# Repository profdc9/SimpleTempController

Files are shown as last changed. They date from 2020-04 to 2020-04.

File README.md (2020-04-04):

This is a simple temperature controller based on an Arduino that is intended to be used with an improvised dry heat disinfection unit that operates at 60 to 100 C.  The disinfection unit uses a small metal bucket and lid as the disinfection chamber and incandescent light bulbs as the heating elements which should be available at hardware stores.  The unit is designed to be readily constructible for use in a crisis or pandemic situation where dry heat disinfection is applied to personal protective equipment (PPE).

It is intentionally simple, requiring the minimum specialized parts, so it can be built with parts that are on-hand or readily available.  The main specialized parts are an Arduino Nano or Arduino Uno and a LM35 temperature sensing IC.  The user interface is four LEDs and three push buttons.  A PCB layout is available for a version that uses the Arduino Nano V3.  The PCB is one-sided an a stencil is provided for etching a circuit board.  Because the disinfection unit uses mains power, precautions should be taken to prevent electric shock.

Directories:

-	code: Arduino project
-	doc: Documents describing how to construct and use the improvised dry heat disinfection unit.
- 	SimpleTempController: KiCad PCB layout.  

The PCB was created by Daniel Marks and is available under the Creative Commons CC-BY-SA 4.0 licenses, and the software was also created by Daniel Marks and is available under the zlib license.  THE HARDWARE AND SOFTWARE IS PROVIDED "AS IS", WITHOUT WARRANTY OF ANY KIND, EXPRESS OR IMPLIED, INCLUDING BUT NOT LIMITED TO THE WARRANTIES OF MERCHANTABILITY, FITNESS FOR A PARTICULAR PURPOSE AND NONINFRINGEMENT. IN NO EVENT SHALL THE AUTHORS OR COPYRIGHT HOLDERS BE LIABLE FOR ANY CLAIM, DAMAGES OR OTHER LIABILITY, WHETHER IN AN ACTION OF CONTRACT, TORT OR OTHERWISE, ARISING FROM, OUT OF OR IN CONNECTION WITH THE HARDWARE AND SOFTWARE OR THE USE OR OTHER DEALINGS IN THE HARDWARE AND SOFTWARE.

For any questions, please contact Daniel Marks, profdc9@gmail.com

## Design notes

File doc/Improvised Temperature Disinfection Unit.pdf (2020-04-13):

An improvised temperature controller for a heat disinfection cabinet by Daniel L. Marks

Rev1: March 29, 2020
Rev2: April 3, 2020
Rev3: April 13, 2020

WARNING:
These instructions are followed at your own risk.
By proceeding further, you agree to take all necessary safety precautions. In no event, should the author of this document be liable for any damages whatsoever. If you live in a jurisdiction that does not allow the exclusion of liabilities, then you should not proceed further. Because this project involves disinfection of deadly pathogens, possible electrocution from mains voltages, possible fire hazards from heating elements, and a variety of other potentially harmful and deadly risks, the author disclaims responsibility for the use of this document. This work is intended as an improvised device to disinfect PPE with dry heating in a pandemic crisis situation. Please take proper precautions around mains power and ensure that overheating does not occur. It is recommended that one read over these directions before starting the project.

Abstract: Studies have shown that the viruses on personal protective equipment (PPE), such as N95 masks, may be deactivated by the application of sufficient heat for a sufficient duration of time while preserving the function of the PPE. Successful treatment requires control of both the temperature and duration of the applied heat. This document describes an improvised heat disinfection cabinet which includes a temperature controller. The heating element is a common non-halogen incandescent light bulb, while the temperature control is construct from commonly available electrical components such as an Arduino Nano, relays, LEDs, and buttons. To construct the incandescent light heater, the constructor should be familiar with precautions taken when working with mains voltages, especially if an existing lamp is modified for this purpose.

It is recommended that one read over these directions before starting the project.

The project github which includes source code, schematics, and a PCB board layout, is located at

http://www.github.com/profdc9/SimpleTempController

Parts necessary for the temperature controller

- Arduino Nano V3, Arduino Nano, or Arduino Uno
- Pin socket headers for the Arduino Nano if it is not to be soldered directly into the PCB.
- LM35 temperature sensing IC in TO-92 package
- 7 1 kW 1/4 watt resistor
- 1 10 kW 1/4 watt resistor
- 1 100 W 1/4 watt resistor

“An improvised temperature controller for a heat disinfection cabinet,” by Daniel L. Marks. Please
refer to the warnings on page one. | 1

- 2 Small single NPN BJTs, examples: 2N2222A, 2N3904, BC548. As seen from the flat side, 2N2222A and 2N3904 have emitter, base, collector left-to-right as viewed from the flat side, while BC548 is the opposite: collector, base, emitter left-to-right as viewed from the flat side.
- 2 Small silicon diodes, examples: 1N4148, 1N4001, 1N4007, etc. The black band corresponds to the cathode, or the terminal of the diode on the schematic with the thin line (not the arrow).
- 1 100 nF ceramic disc capacitor, 25 volts
- 4 LEDs (any color)
- 3 Single pole-single throw (SPST) momentary contact (push button) normally open switch. If possible, make button #3 a different color (by selection or marking) than buttons #1 and #2. For example, make button #3 red and buttons #1 and #2 black. This is because one can simply instruct a user to turn on the device and press the red button to start the heating cycle.
- 1 Single-pole single-throw (SPST) or single-pole double throw (SPDT) 5 volt coil relay, 250 VAC voltage rated relay. Example: SONGLE SRD-05VDC-SL-C relay. A module such as shown below is better for connection because it has screw terminals but may not be available.

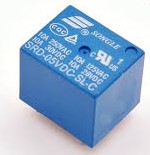
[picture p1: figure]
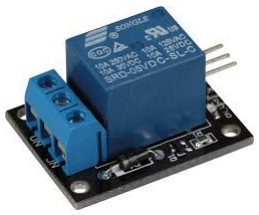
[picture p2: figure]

- Optional: a small piezo disc transducer or audio speaker to obtain an audible alarm.
- A 5 volt, 500 mA minimum USB power adapter with USB B/mini-B/micro-B cable to plug into the Arduino.
- A PCB, either the PCB designed by the author, or a prototyping board, solderless breadboard, or perf board as available. The PCB designed by the author is a single-layer board that can be fabricated using one-sided PCB etching.
- An insulating plastic enclosure for the PCB.

Constructing the circuit

The most likely available construction material for the PCB is a perf board. It can be constructed using point-to-point connections between the components. A solderless breadboard may be used as well, however, this has the risk that wires may become loose. The author constructed the circuit on a perf board as shown below:

“An improvised temperature controller for a heat disinfection cabinet,” by Daniel L. Marks. Please

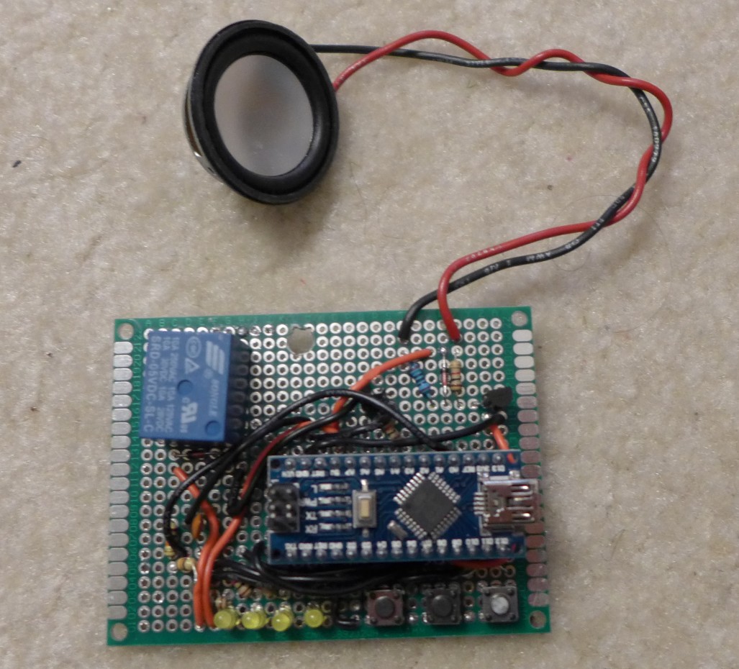
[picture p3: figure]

Special care was taken to ensure that the relay pole, normally open, and normally closed contacts are well isolated. This is to ensure that when mains is attached to the relay, there is no accidental bridge to the coil of the relay or any other part of the circuit. There

“An improvised temperature controller for a heat disinfection cabinet,” by Daniel L. Marks. Please

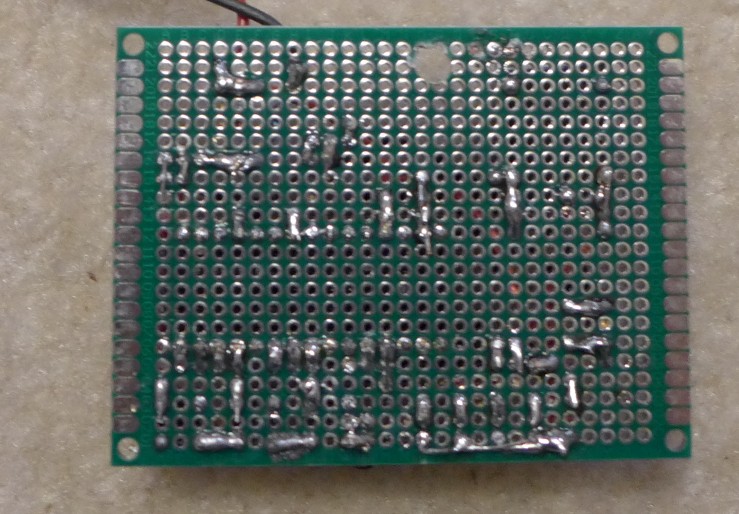
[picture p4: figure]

The relay contacts are in the upper-right corner. Solder bridges between neighboring perforated hole are to be avoided at the relay contacts. A hole has been drilled through the PCB near the relay. This is to insert a cable tie which will later be used for strain relief to prevent the extension cord wires from tugging on the solder joints.

Parts necessary for the heating elements

NOTE: The following procedure is probably violating all kinds of electrical codes. If you have the means of making a properly enclosed and grounded device, then you should do so. If you can get a relay module with screw terminals already connected to the relay, that is also better than soldering directly to the relay terminals as is shown here. However, we assume that this may not be possible because electronic supply services may be unavailable and relays may need to be scavenged from other equipment.

- A 3-prong extension cord (including hot, neutral, and earth ground) that will be modified.
- A metal bucket with lid as an enclosure, for example, this 6 gallon or 22 L bucket:

“An improvised temperature controller for a heat disinfection cabinet,” by Daniel L. Marks. Please

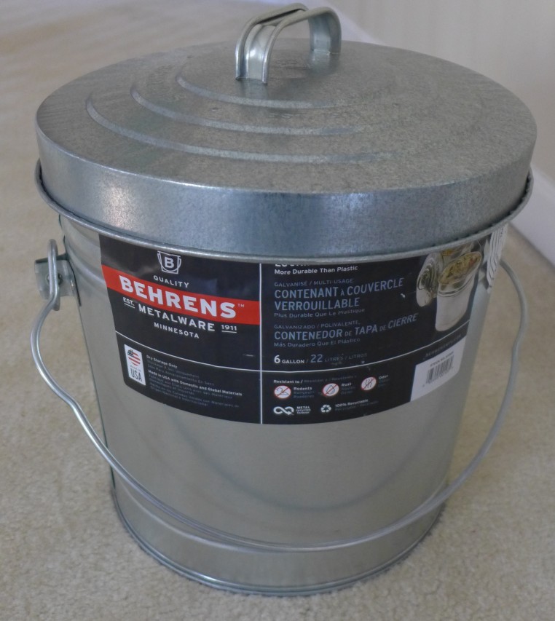
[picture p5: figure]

- Another power 3-prong power cord that is cut from a device (typically salvaged from broken equipment).
- A short length of mains hookup wire (105°C, 600 V or higher rated such as THHN)
- Two ceramic or phenolic light fixtures.
- Two 60 watt incandescent light bulbs.
- A block to mount the incandescent the light fixtures on.
- A screw, washer, and nut (M3/M4 or SAE 6-32/8-32 size).
- Cable ties and electrical tape.
- Standoffs and screws for the PCB.

Directions:

Drill three holes in the side of the bucket near the bottom.

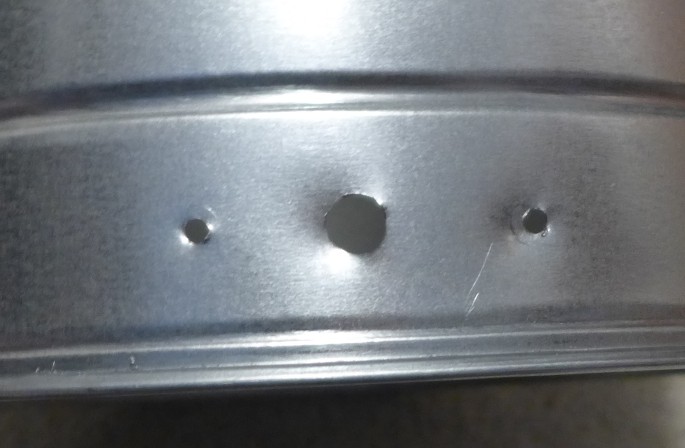
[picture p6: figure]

“An improvised temperature controller for a heat disinfection cabinet,” by Daniel L. Marks. Please

The larger hole is used for the power cord. One of the small holes is used for the temperature sensor, and the other small hole is used to attach a grounding lug. Insert the power cord through the hole like this:

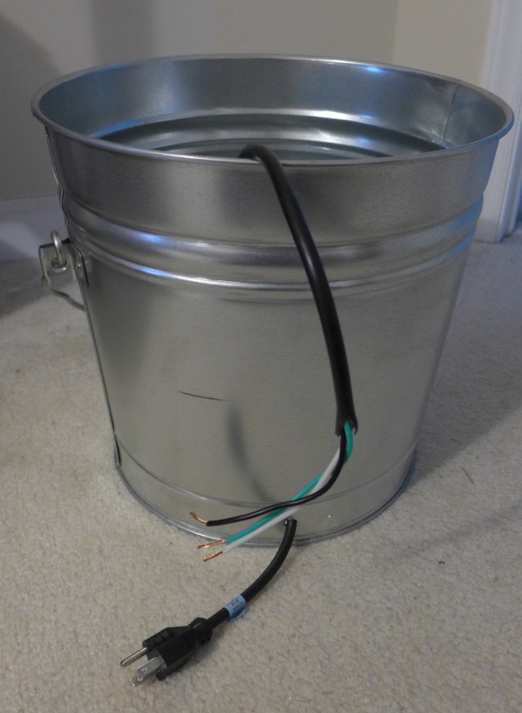
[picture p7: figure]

Attach the two light sockets as shown below. The gold colored contacts on the sockets are the hot contacts, and are connected to the hot black wire. The silver colored contacts on the sockets are the neutral contacts, and are connected to the white wire. Leave the green earth ground wire unconnected presently. For European cords, the hot color is brown, the neutral color is blue, and the earth ground is yellow and green striped.

“An improvised temperature controller for a heat disinfection cabinet,” by Daniel L. Marks. Please

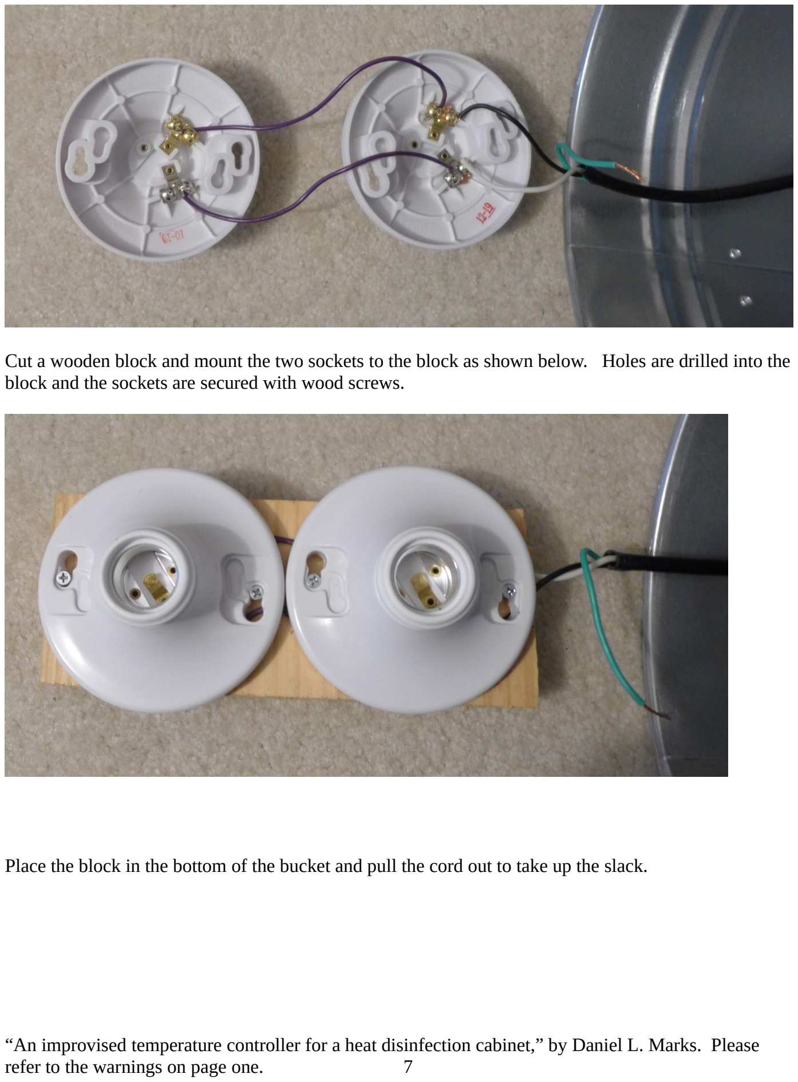
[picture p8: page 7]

Cut a wooden block and mount the two sockets to the block as shown below. Holes are drilled into the block and the sockets are secured with wood screws.

Place the block in the bottom of the bucket and pull the cord out to take up the slack.

“An improvised temperature controller for a heat disinfection cabinet,” by Daniel L. Marks. Please

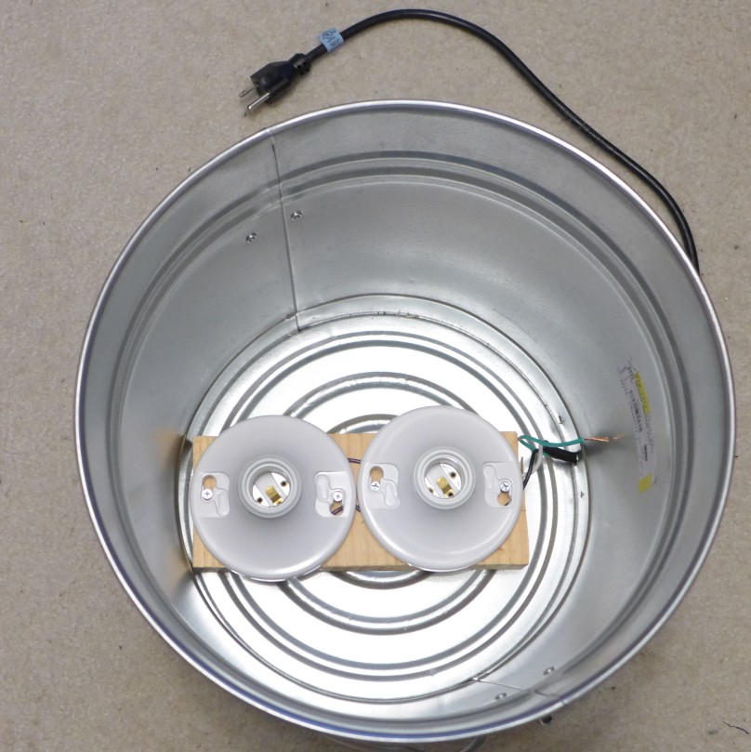
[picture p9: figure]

Where the cord enters the bucket, wrap the cord with some electric tape. This tape will serve to protect the cord from the rough edge of the metal as a makeshift strain relief.

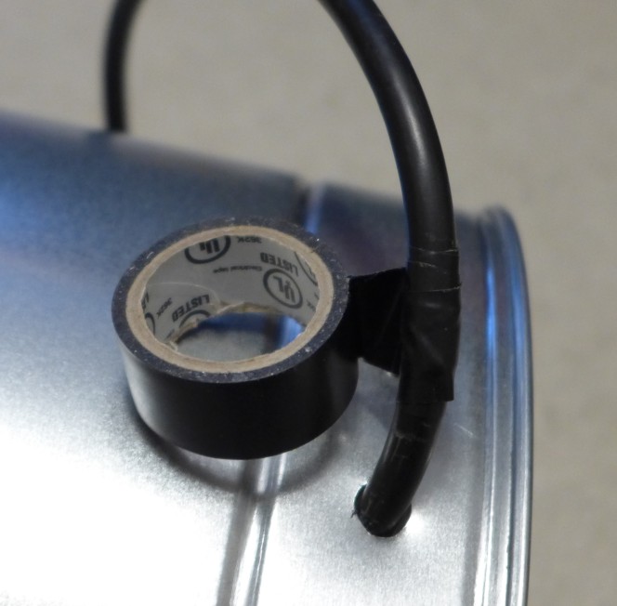
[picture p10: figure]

“An improvised temperature controller for a heat disinfection cabinet,” by Daniel L. Marks. Please

Pull the cord into the bucket so that the electrical tape is pressed up against the edges of the hole. Then tighten two cable ties as close to the wall of the bucket on either side of the cable to immobilize the cable. Cut away the excess cable tie material.

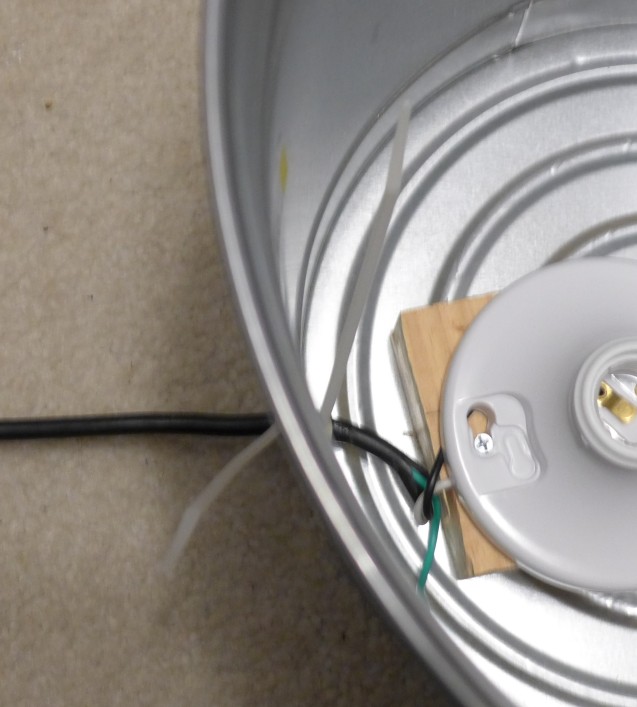
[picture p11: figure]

Using the screw, washer, and nut, insert the screw through a narrow hole outside the bucket. Place a washer and nut on the screw on the other side. Take the earth ground wire and curl it between the washer and the side of the bucket. Tighten the screw to clamp the earth ground wire into contact with the bucket.

“An improvised temperature controller for a heat disinfection cabinet,” by Daniel L. Marks. Please

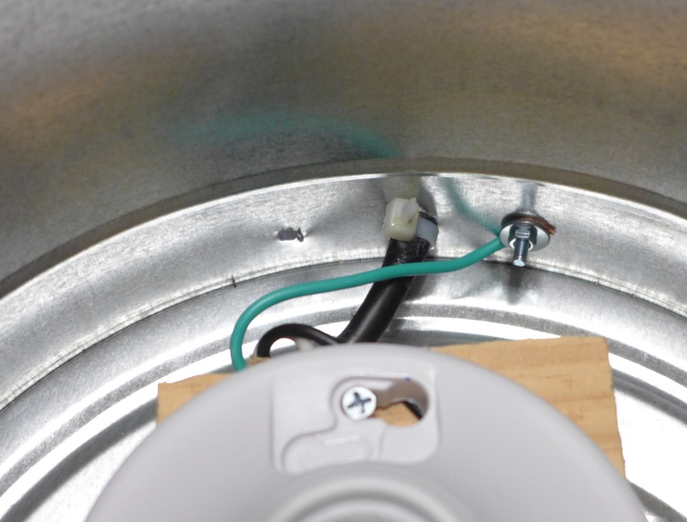
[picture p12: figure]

Insert light bulbs into the socket. To test the bucket, it may be plugged into the wall to see if the bulbs light.

Attaching the extension cord to the controller PCB

To protect the PCB and the mains connections, we place the PCB into a plastic enclosure. We first mark the positions for the standoffs on the bottom of the enclosure using the PCB as a template.

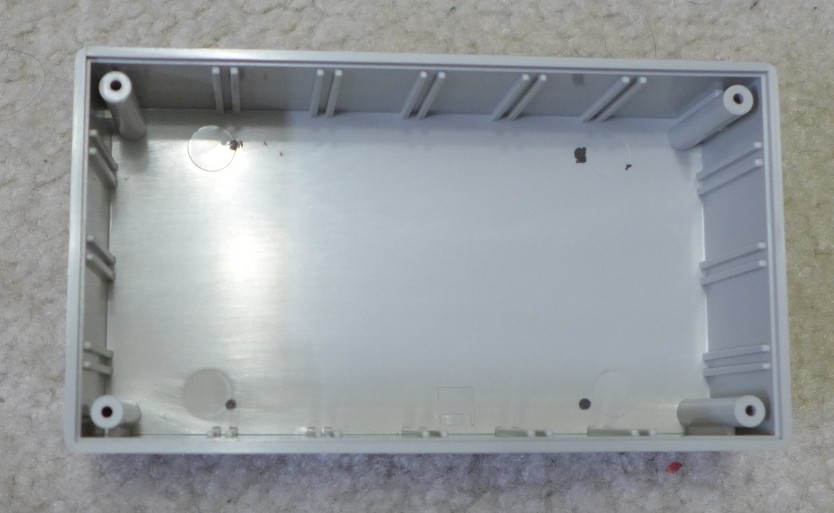
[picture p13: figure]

Drill holes for the standoffs and holes in the side of the box for the extension cord to enter and leave the enclosure. Cut the extension cord (after unplugging from mains!) and insert both ends into the box. Strip the insulation from the end of the wires.

“An improvised temperature controller for a heat disinfection cabinet,” by Daniel L. Marks. Please

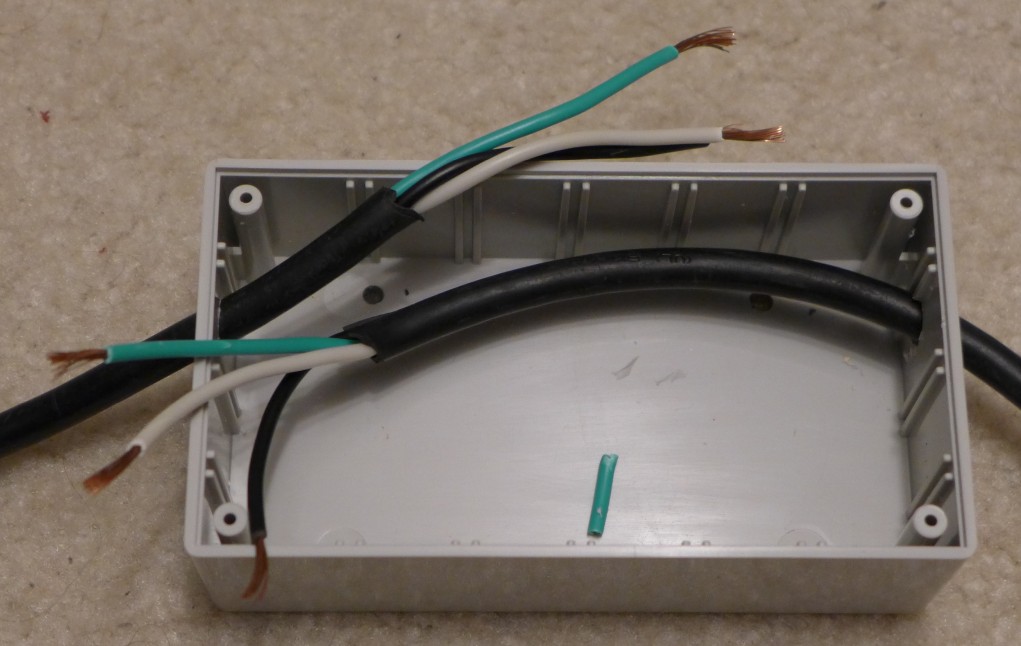
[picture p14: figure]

Rejoin the white neutral and green earth ground wires by twisting and soldering them together. If you have heat shrink tubing, this can be placed on the wires before soldering and used to insulate the joint. Otherwise, careful wrapping in electrical tape is sufficient.

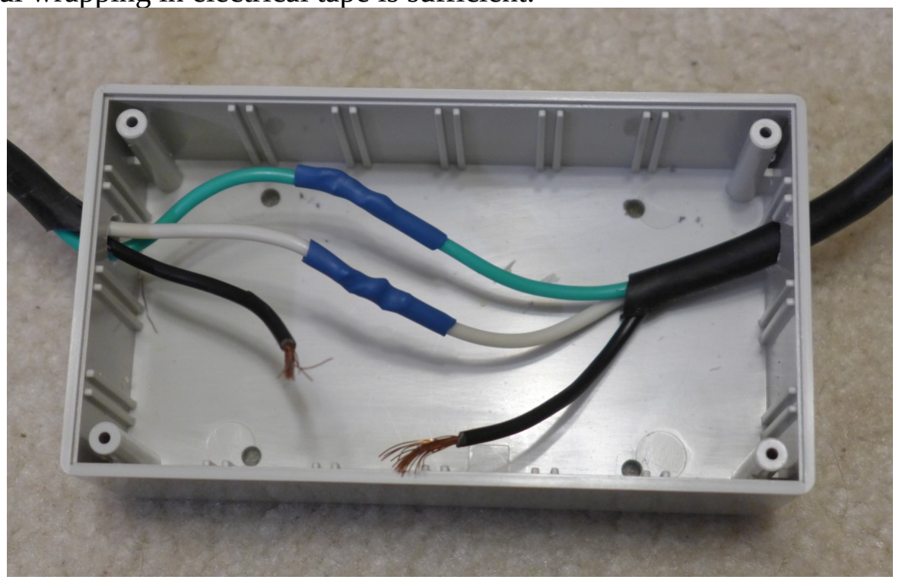
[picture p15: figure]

Cut the two black wires so that only a few millimeters of conduct is present. Tin the ends of the two black wires with solder as well as the normally open and pole contacts of the relay. Then join one of the black wires with the pole contact and the other black wire to the normally open contact. Make sure the black wires are oriented as to not make contact with any other parts of the circuit especially the coil contacts.

“An improvised temperature controller for a heat disinfection cabinet,” by Daniel L. Marks. Please

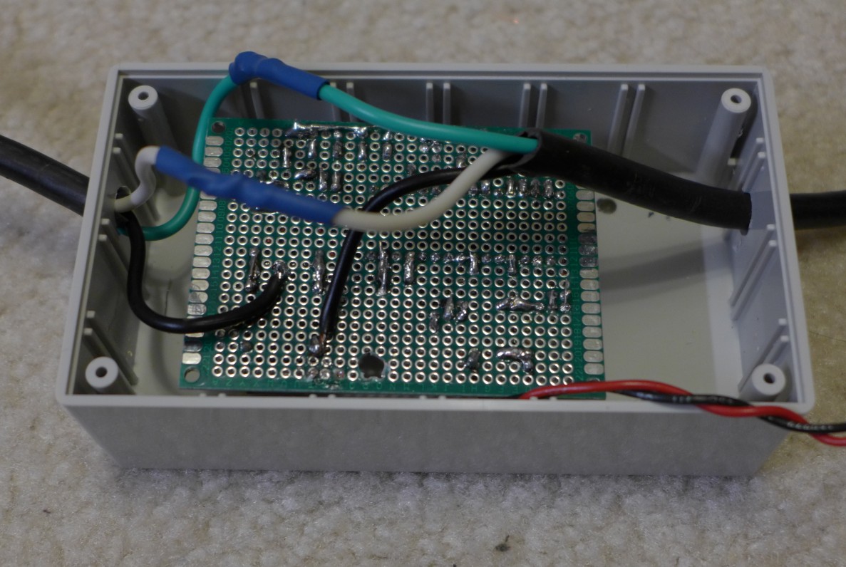
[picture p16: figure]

A
Insert a cable tie through the hole drilled in the PCB, and then fasten the cable tie around the conductor wires of the extension cord. This provides strain relief to the solder contacts to the relay.

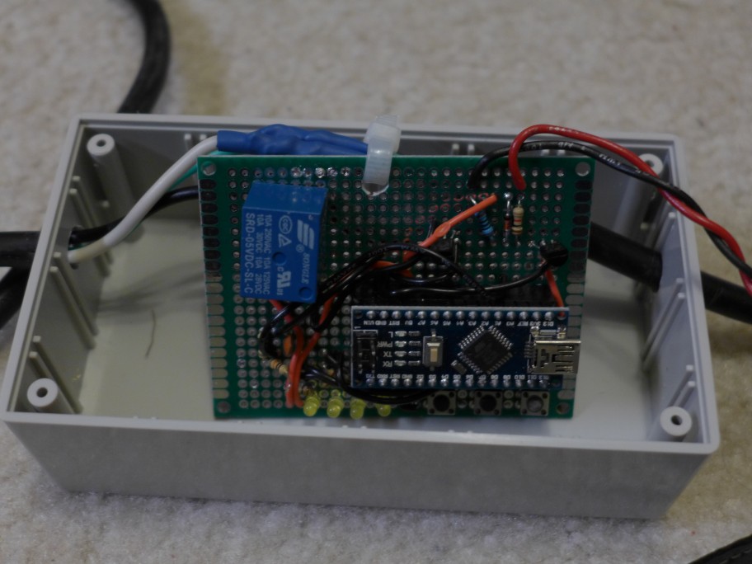
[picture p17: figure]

Using a file or a rotary tool, cut a hole for the USB cable and temperature probe. Use cable ties on both sides of the extension cord where the extension cord enters and leaves the plastic enclosure to immobilize the cable and provide strain relief.

“An improvised temperature controller for a heat disinfection cabinet,” by Daniel L. Marks. Please

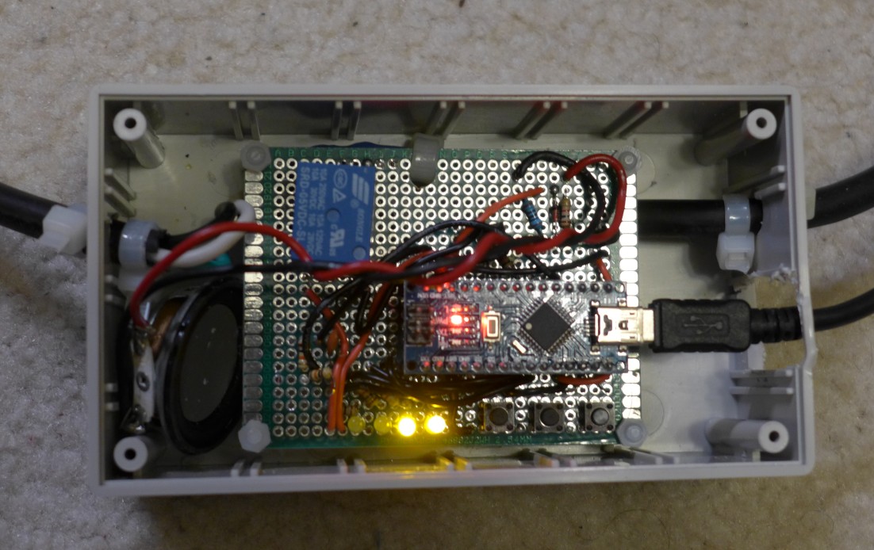
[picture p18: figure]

Solder the LM35 temperature module to three wires. Looking from the flat side of the LM35 IC, the leads indicate VCC, TEMP, and GND. The cable below is a four conductor cable used for connecting telephones with one conductor cut off. An ethernet cable may also be used as a multiconductor cable, as the typical ethernet cable contains four twisted pairs. Heat shrink tubing is placed over the wires if available to insulate the connections from each other, or electrical tape is used if not available.

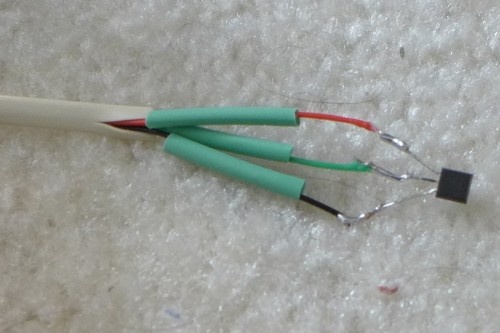
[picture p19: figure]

Heat shrink tubing is applied over all of the temperature probe wires to bind them together, or alternatively electrical tape is wrapped around all of the wires.

“An improvised temperature controller for a heat disinfection cabinet,” by Daniel L. Marks. Please

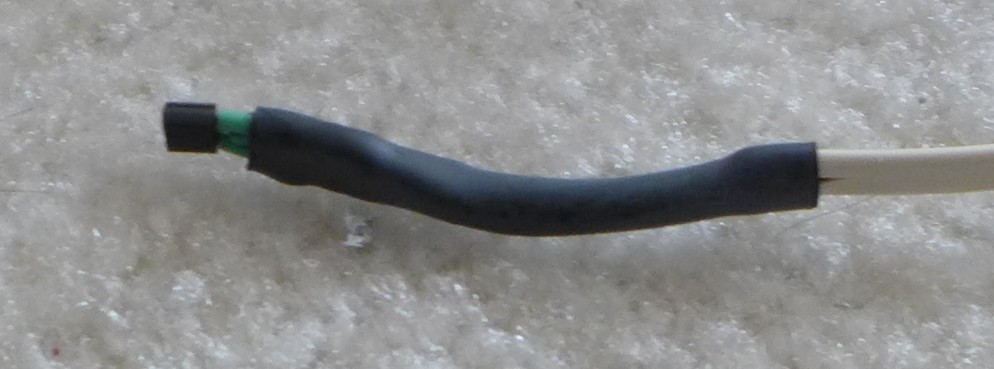
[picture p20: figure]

Place the probe in the bucket and feed the end of the wire through the bucket. Position the probe at the bottom of the bucket, preferably in the shadow of the block to minimze direct illumination of the probe. Solder the three wires to the appropriate places on the PCB for power, ground, and the temperature connection as shown in the schematic. Use a cable tie to affix the temperature probe wires to the extension cord to strain relief the wires so that the solder joints on the PCB are not tugged on by the temperature probe wires. Mount the PCB to the case using the standoffs.

To assemble the system, plug the light bulb heaters into the end of the extension cord, the extension cord into mains power, and the USB power adapter into the Arduino.

Programming the Software

The software is a single file Arduino project. The Arduino programming environment should be installed on your computer. When plugged into a computer, the Arduino appears as a COM or serial port. This COM port should be selected in the Arduino environment. Furthermore, the board selected should be “Arduino Nano” and the processor is “ATMega328P.” Note that if your Arduino Nano uses the CH340G serial chip rather than the standard FTDI-based chip, the “ATMega328P (Old Bootloader)” option should be selected instead. Load the Arduino project and select “Upload.” The project should be compiled and uploaded to the processor, and the processor will execute the software, flashing the code

■ ■ □ □ | □ □ ■ ■

if successful.

“An improvised temperature controller for a heat disinfection cabinet,” by Daniel L. Marks. Please

Using the temperature controller

The temperature has three buttons and four LEDs that indicate the state of the controller. The interface is intentionally kept basic and constructable from simple parts. The three buttons are referred to by the numbers #1, #2, and #3. The state of the four LEDs are shown in the following way:

■ | Filled square indicates LED is on
□ | Empty square indicates LED is off
■ □ ■ □ | The four LEDs are in the pattern on, off, on, off.

To avoid confusion, the mirror image of the four LED pattern is never used to indicate a different state, so for example

■ □ ■ □ | and | □ ■ □ ■

are the same indication.

When the controller is first turned on, the following pattern is flashed on the display:

■ ■ □ □ | □ □ ■ ■

At this point, one can select three options:

- Select the temperature by pressing and holding button #1 for five seconds. The display will flicker while the button is held.
- Select the duration of the cycle by pressing and holding button #2 for five seconds. The display will flicker while the button is held.
- Start the heating cycle by pressing and holding button #3 for one-half second. The display will flicker while the button is held.

If the device has no configuration, the default is 70○C temperature, 30 minutes heating cycle, and 2○C hysteresis.

Selecting the temperature:

Selecting the temperature is first initiated by pressing and holding button #1 for five seconds when the controller is flashing the code ■ ■ □ □ / □ □ ■ ■. The following sequence cycles several times on the display to show that the temperature set point option is selected:

■ □ □ □ | □ ■ □ □ | □ □ ■ □ | □ □ □ ■

A code then flashes on the LEDs to indicate the selected temperature. By pressing button #2, one may cycle through the options for temperature. By pressing button #1, the temperature is selected.

■ □ □ □ | 60○C | □ ■ □ □ | 65○C

“An improvised temperature controller for a heat disinfection cabinet,” by Daniel L. Marks. Please

■ ■ □ □ | 70○C | ■ □ ■ □ | 75○C
■ □ □ ■ | 80○C | ■ ■ □ ■ | 90○C
■ ■ ■ ■ | 100○C

Selecting the duration:

Selecting the duration for which the heat is maintained at the target temperature is first initiated by pressing and holding button #2 for five seconds when the controller is flashing the code
■ ■ □ □ / □ □ ■ ■. The following sequence cycles several times on the display to show that the duration set option is selected:

■ □ □ ■ □ ■ ■ □

A code then flashes on the LEDs to indicate the selected temperature. By pressing button #2, one may cycle through the options for temperature. By pressing button #1, the temperature is selected.

■ □ □ □ | 10 minutes | □ ■ □ □ | 20 minutes
■ ■ □ □ | 30 minutes | ■ □ ■ □ | 45 minutes
■ □ □ ■ | 60 minutes | ■ ■ □ ■ | 90 minutes
■ ■ ■ ■ | 120 minutes

Selecting the hysteresis temperature:

In some cases, the controller may cycle rapidly between turning the heating element on and off while in the heating cycle. This is because the controller is responding too quickly to changes in temperature. To prevent this, the hysteresis of the controller is adjustable. The hysteresis setting determines the temperatures the controller turns the heating element on and off. For a given hysteresis temperature, the controller turns off the element when the temperature is over the set point by the hysteresis temperature, and turns back on the element when the temperature is below the sent point by the hysteresis temperature. For example, if the hysteresis temperature is 4

○C, and the set point is 70○C, the heating element is turned off when the temperature exceeds 74○C, and the heating element is turned on when the temperature is below 66○C.

To select the hysteresis, first press and hold button #1 for five seconds when the controller is flashing the code ■ ■ □ □ / □ □ ■ ■ as if the temperature is being changed. The following sequence cycles several times on the display to show that this temperature set point option is selected:

■ □ □ □ | □ ■ □ □ | □ □ ■ □ | □ □ □ ■

The mode to select the target temperature is entered. Next, press and hold button #3 for five seconds. Then the following sequence cycles several times on the display to show that the hysteresis set point option is selected:

■ □ □ □ | □ □ □ ■ | □ ■ □ □ | □ □ ■ □

“An improvised temperature controller for a heat disinfection cabinet,” by Daniel L. Marks. Please

A code then flashes on the LEDs to indicate the selected hysteresis temperature. By pressing button #2, one may cycle through the options for hysteresis temperature. By pressing button #1, the hysteresis temperature is selected.

■ □ □ □ | 1
○C | □ ■ □ □ | 2

○C
■ ■ □ □ | 3
○C | ■ □ ■ □ | 4

○C
■ □ □ ■ | 5
○C | ■ ■ □ ■ | 6

○C
■ ■ ■ ■ 7

○C

Staring the heating cycle:

Before starting the heating cycle, the heating element, temperature sensor, and object to the disinfected should be placed into the enclosure and the enclosure closed. To initiate the disinfection cycle, press and hold button #3 for one-half second when the controller is flashing the code ■ ■ □ □ / □ □ ■ ■.

The initial heating part of the cycle will begin. The heating element will turn on and continues until the temperature reaches the target temperature. This is indicated on the LEDs by the following alternating pattern:

■ □ ■ □ □ ■ □ ■

The time required to reach the target temperature depends on the heating element power, the size of the enclosure, how well the enclosure is insulated, and the target temperature. Once the target temperature is reached, the second part of the heating cycle initiated. The temperature is held at the selected target temperature for the selected duration. During this cycle, the following codes are shown on the LEDs:

■ □ □ □ | Code during the first quarter of the cycle duration.
■ ■ □ □ | Code during the second quarter of the cycle duration.
■ □ ■ □ | Code during the third quarter of the cycle duration.
■ □ □ ■ | Code during the last quarter of the cycle duration.

If the heating element is presently on, the rightmost LED is flashing, otherwise it remains constantly on. Once the second part of the heating cycle is completed, the entire cycle is completed and the heating element is turned off, and the following code is flashed:

■ ■ ■ ■ □ □ □ □

Pressing any of the buttons ends the cycle. Any time during the cycle, button #1 may be pressed and held for one second to terminate the cycle prematurely.

If there is a problem during the heating cycle, the heating cycle is terminated, the heating element is turned off, the following error code is flashed:

■ □ □ ■ □ □ □ □

“An improvised temperature controller for a heat disinfection cabinet,” by Daniel L. Marks. Please

Any of the three buttons can be pressed to clear the error code. The error can occur for the following reasons:

- The temperature probe is faulty or is detecting an invalid temperature, which is either below 2

○C or above 200○C.
- During the initial part of the heating cycle, a temperature more than 10○C higher than the target temperature is measured.
- During the second part of the heating cycle, a temperature more than 10○C higher than the target temperature, or less than 10○C below the target temperature, is measured.

In case of this error, check the following conditions, powering off the temperature controller and heating element first and disconnecting them/unplugging from mains power:

- Ensure that all three wires (power, ground, and temperature signal) to the LM35 integrated circuit are connected. Measure the voltages of these signals both at the sensor and the controller, with the heating element disconnected from power, to ensure the connection is based.
- Ensure that the heating element is turning on during the initial cycle, that the incandescent bulb is not burned out, and that the power switch is on to the lamp (if present).
- Ensure that all soldered and/or wire nut connections are secure.
- Ensure there is no damage to the heating element or lamp that could indicate burning of the insulation on the wires or a short circuit of the wires.
- Inspect the enclosure for any signs of damage, especially around the heating element that could indicate excessive heat, charring, or pyrolysis.

Because this is an improvised enclosure using a heating element, the enclosure should be monitored, especially when it is first being used, to ensure that the enclosure or its contents are not damaged by the heating.

“An improvised temperature controller for a heat disinfection cabinet,” by Daniel L. Marks. Please

Appendix A. Circuit schematics

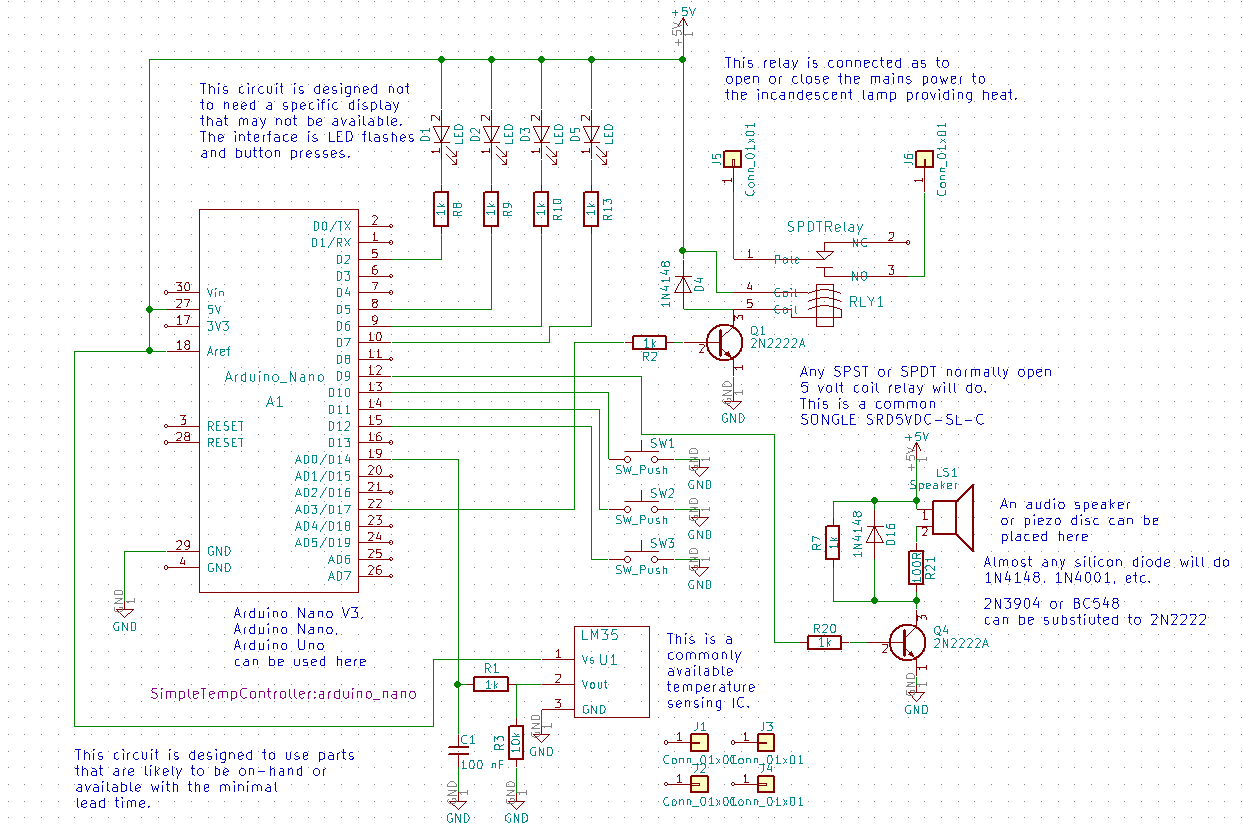
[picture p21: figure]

“An improvised temperature controller for a heat disinfection cabinet,” by Daniel L. Marks. Please

Appendix B. Single Layer PCB Layout

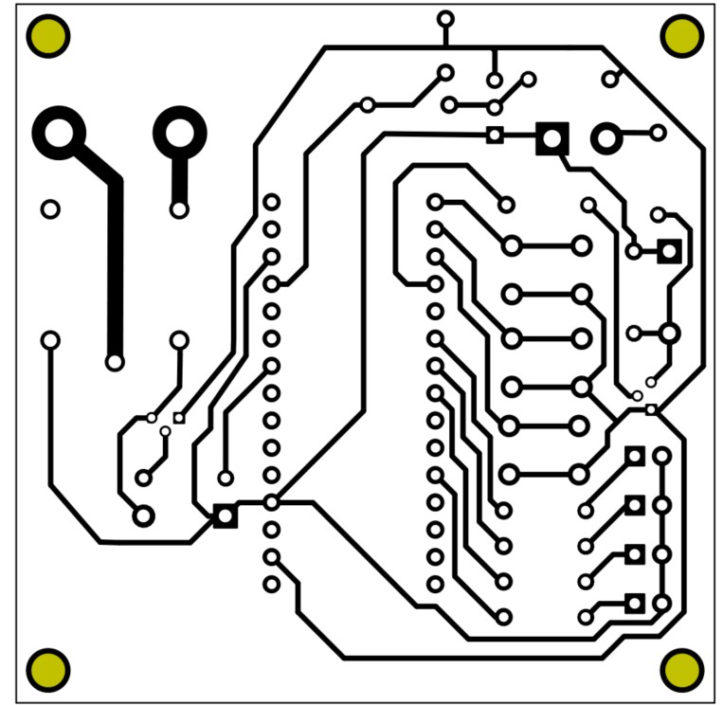
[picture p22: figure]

The dimensions of the board are 65 mm by 65 mm.

“An improvised temperature controller for a heat disinfection cabinet,” by Daniel L. Marks. Please

Appendix C. PCB appearance and component placement

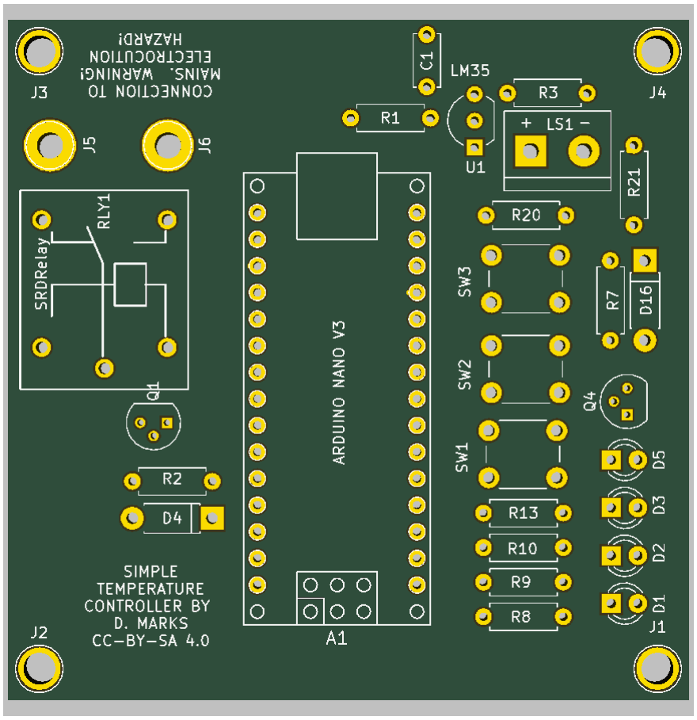
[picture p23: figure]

“An improvised temperature controller for a heat disinfection cabinet,” by Daniel L. Marks. Please

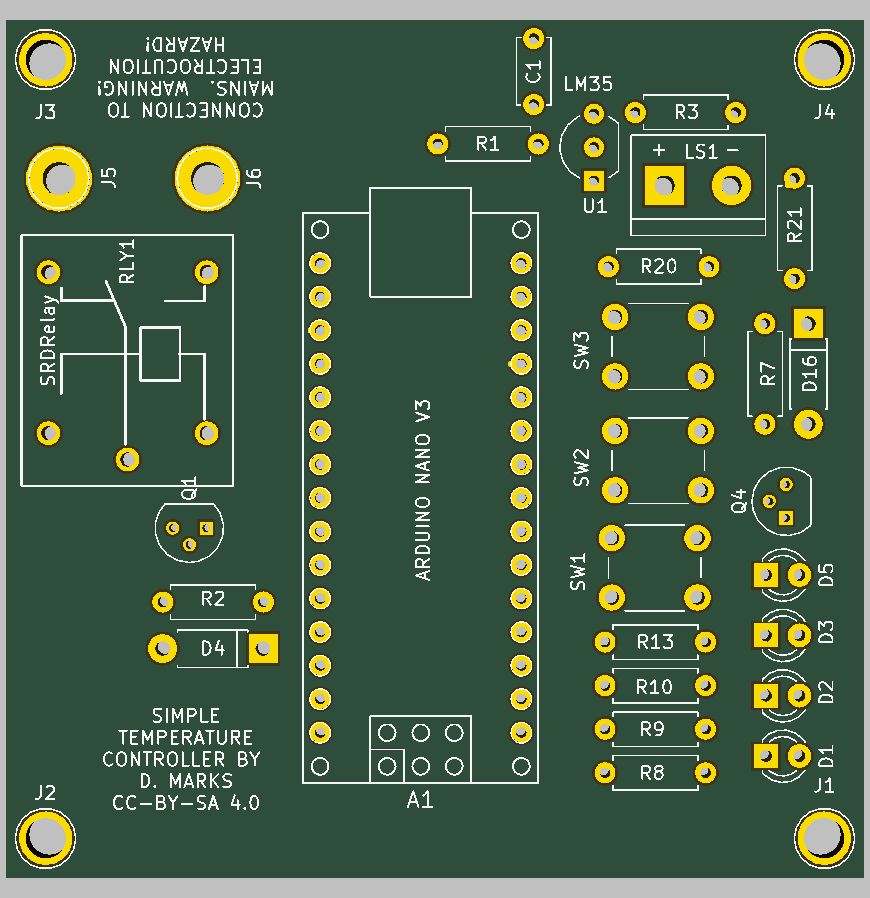
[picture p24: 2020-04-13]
SimpleTempController/SimpleTempController.png

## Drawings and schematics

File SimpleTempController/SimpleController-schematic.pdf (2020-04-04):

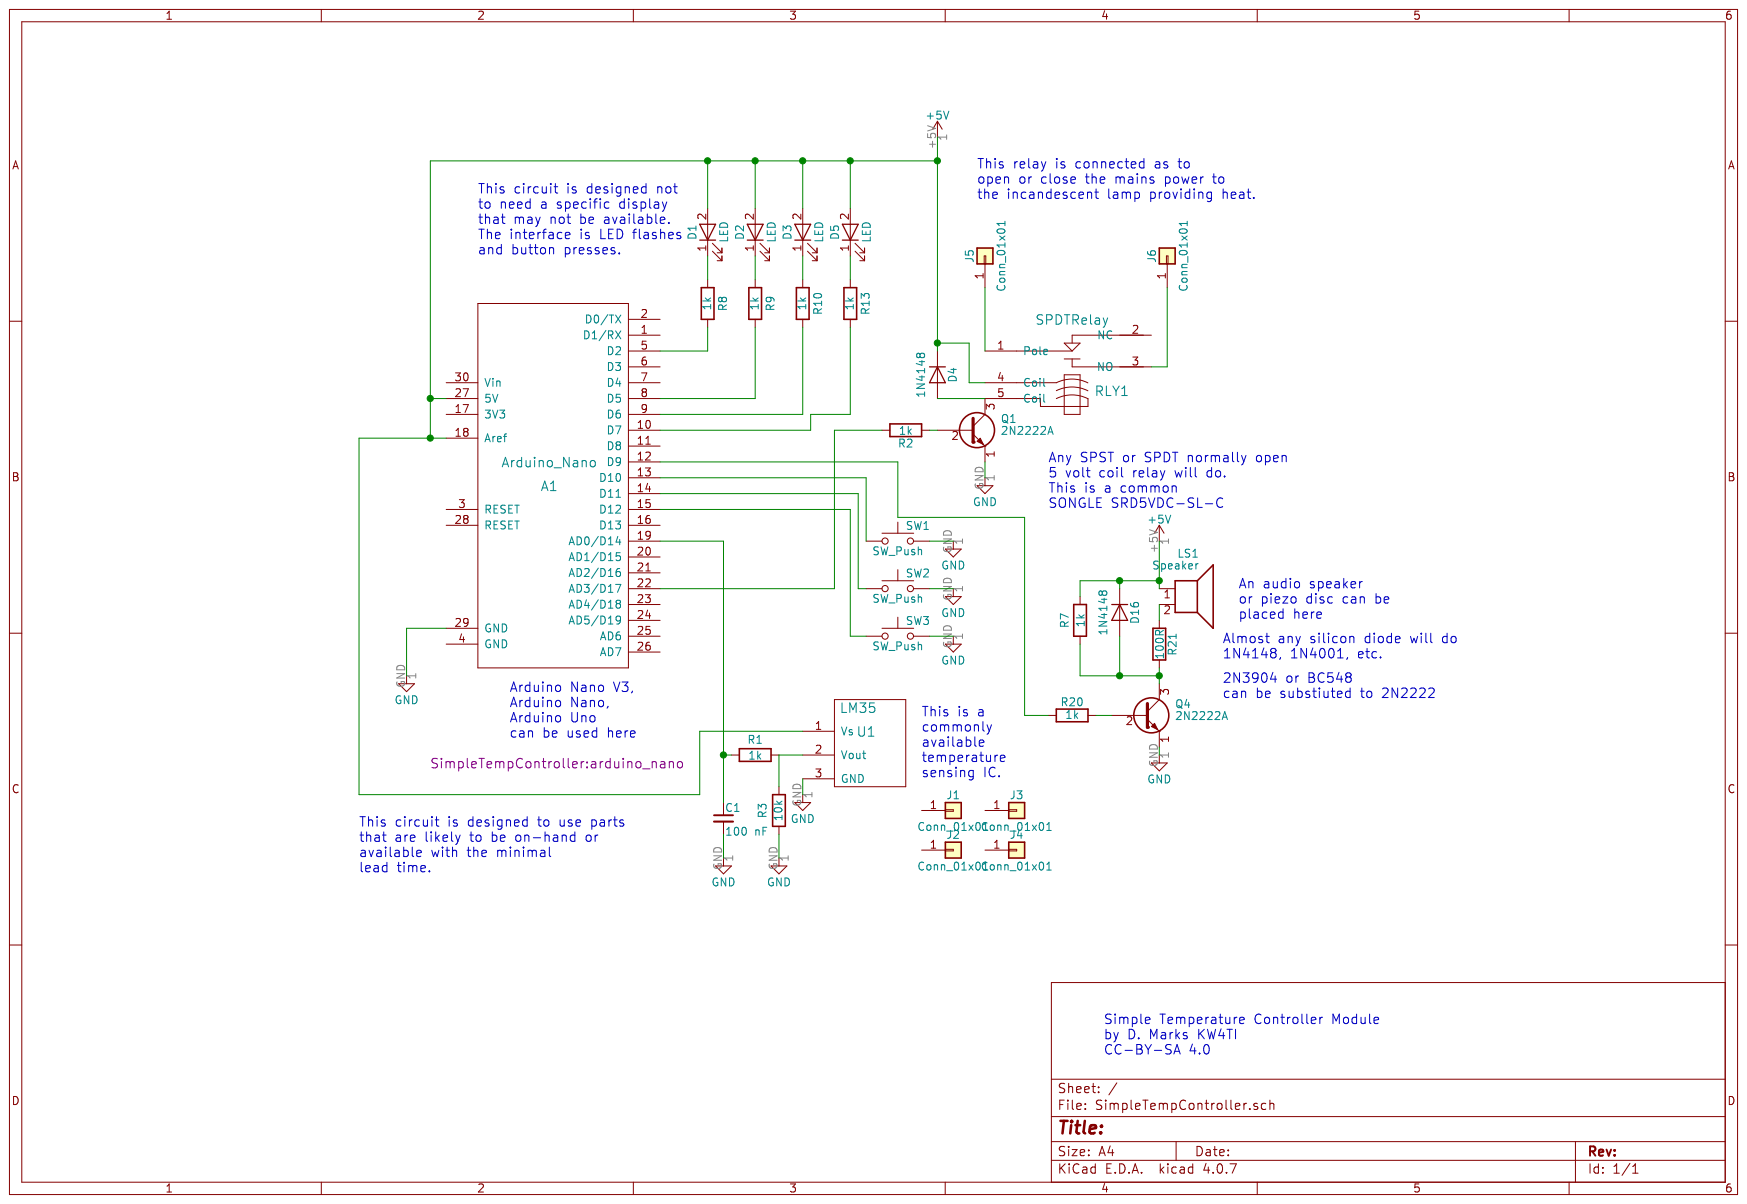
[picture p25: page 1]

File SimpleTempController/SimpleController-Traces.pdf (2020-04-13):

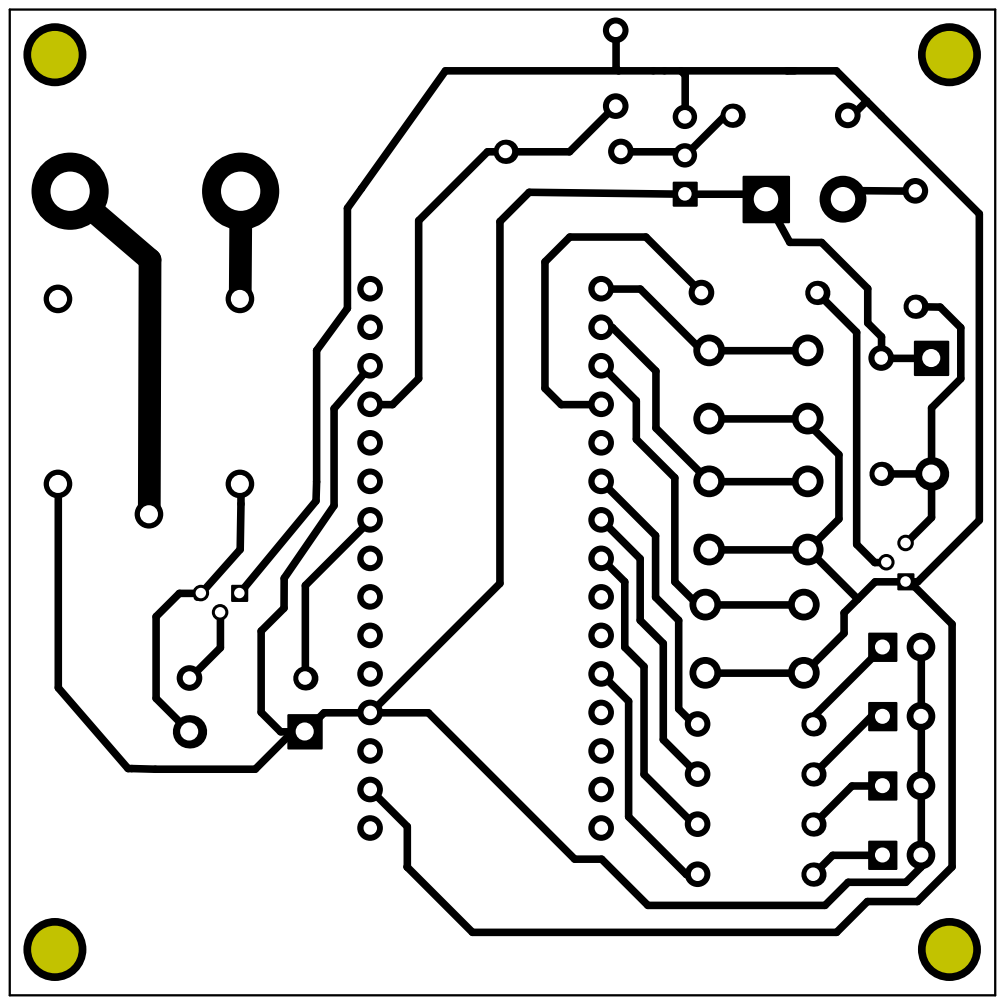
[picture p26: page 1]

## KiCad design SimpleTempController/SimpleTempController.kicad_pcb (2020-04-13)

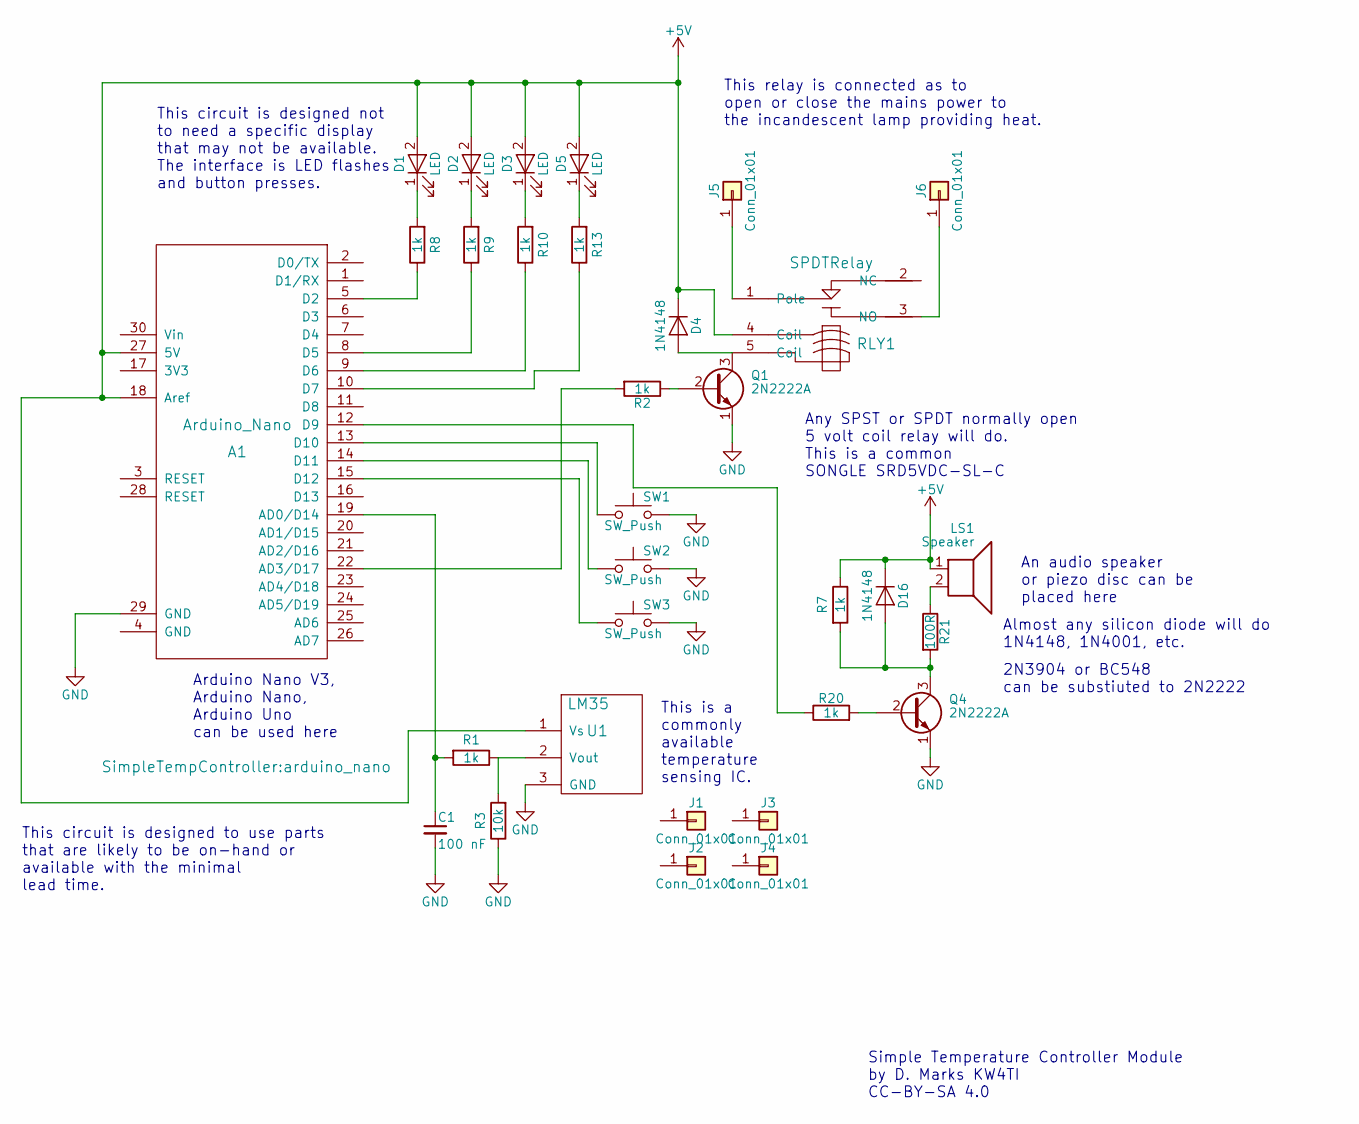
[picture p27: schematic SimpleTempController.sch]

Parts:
A1: Arduino_Nano; arduino_nano
C1: 100 nF; C_Disc_D5.0mm_W2.5mm_P5.00mm
D1, D2, D3, D5: LED; LED_D3.0mm
D4, D16: 1N4148; D_DO-41_SOD81_P7.62mm_Horizontal
J1, J2, J3, J4, J5, J6: Conn_01x01; 1pin
LS1: Speaker; TerminalBlock_bornier-2_P5.08mm
Q1, Q4: 2N2222A; TO-92_Molded_Narrow
R1, R2, R7, R8, R9, R10, R13, R20: 1k; R_Axial_DIN0207_L6.3mm_D2.5mm_P7.62mm_Horizontal
R3: 10k; R_Axial_DIN0207_L6.3mm_D2.5mm_P7.62mm_Horizontal
R21: 100R; R_Axial_DIN0207_L6.3mm_D2.5mm_P7.62mm_Horizontal
RLY1: SPDTRelay; SRDXXRelay
SW1, SW2, SW3: SW_Push; SW_PUSH_6mm
U1: LM35; TO-92_Inline_Wide

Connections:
+5V: A1.18 (Aref), A1.27 (5V), D1.2 (A), D2.2 (A), D3.2 (A), D4.1 (K), D5.2 (A), D16.1 (K), LS1.1, R7.1, RLY1.4 (Coil), U1.1 (Vs)
GND: A1.29 (GND), C1.2, Q1.1 (E), Q4.1 (E), R3.1, SW1.2, SW2.2, SW3.2, U1.3 (GND)
unnamed: A1.5 (D2), R8.1
unnamed: A1.8 (D5), R9.1
unnamed: A1.9 (D6), R10.1
unnamed: A1.10 (D7), R13.1
unnamed: A1.12 (D9), R20.1
unnamed: A1.13 (D10), SW1.1
unnamed: A1.14 (D11), SW2.1
unnamed: A1.15 (D12), SW3.1
unnamed: A1.19 (AD0/D14), C1.1, R1.2
unnamed: A1.22 (AD3/D17), R2.2
unnamed: D1.1 (K), R8.2
unnamed: D2.1 (K), R9.2
unnamed: D3.1 (K), R10.2
unnamed: D4.2 (A), Q1.3 (C), RLY1.5 (Coil)
unnamed: D5.1 (K), R13.2
unnamed: D16.2 (A), Q4.3 (C), R7.2, R21.2
unnamed: J5.1, RLY1.1 (Pole)
unnamed: J6.1, RLY1.3 (NO)
unnamed: LS1.2, R21.1
unnamed: Q1.2 (B), R2.1
unnamed: Q4.2 (B), R20.2
unnamed: R1.1, R3.2, U1.2 (Vout)

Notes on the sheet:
Simple Temperature Controller Module by D. Marks KW4TI CC-BY-SA 4.0
Any SPST or SPDT normally open 5 volt coil relay will do. This is a common SONGLE SRD5VDC-SL-C
This relay is connected as to open or close the mains power to the incandescent lamp providing heat.
An audio speaker or piezo disc can be placed here
This circuit is designed not to need a specific display that may not be available. The interface is LED flashes and button presses.
Almost any silicon diode will do 1N4148, 1N4001, etc.
2N3904 or BC548 can be substiuted to 2N2222
Arduino Nano V3, Arduino Nano, Arduino Uno can be used here
This circuit is designed to use parts that are likely to be on-hand or available with the minimal lead time.
This is a commonly available temperature sensing IC.

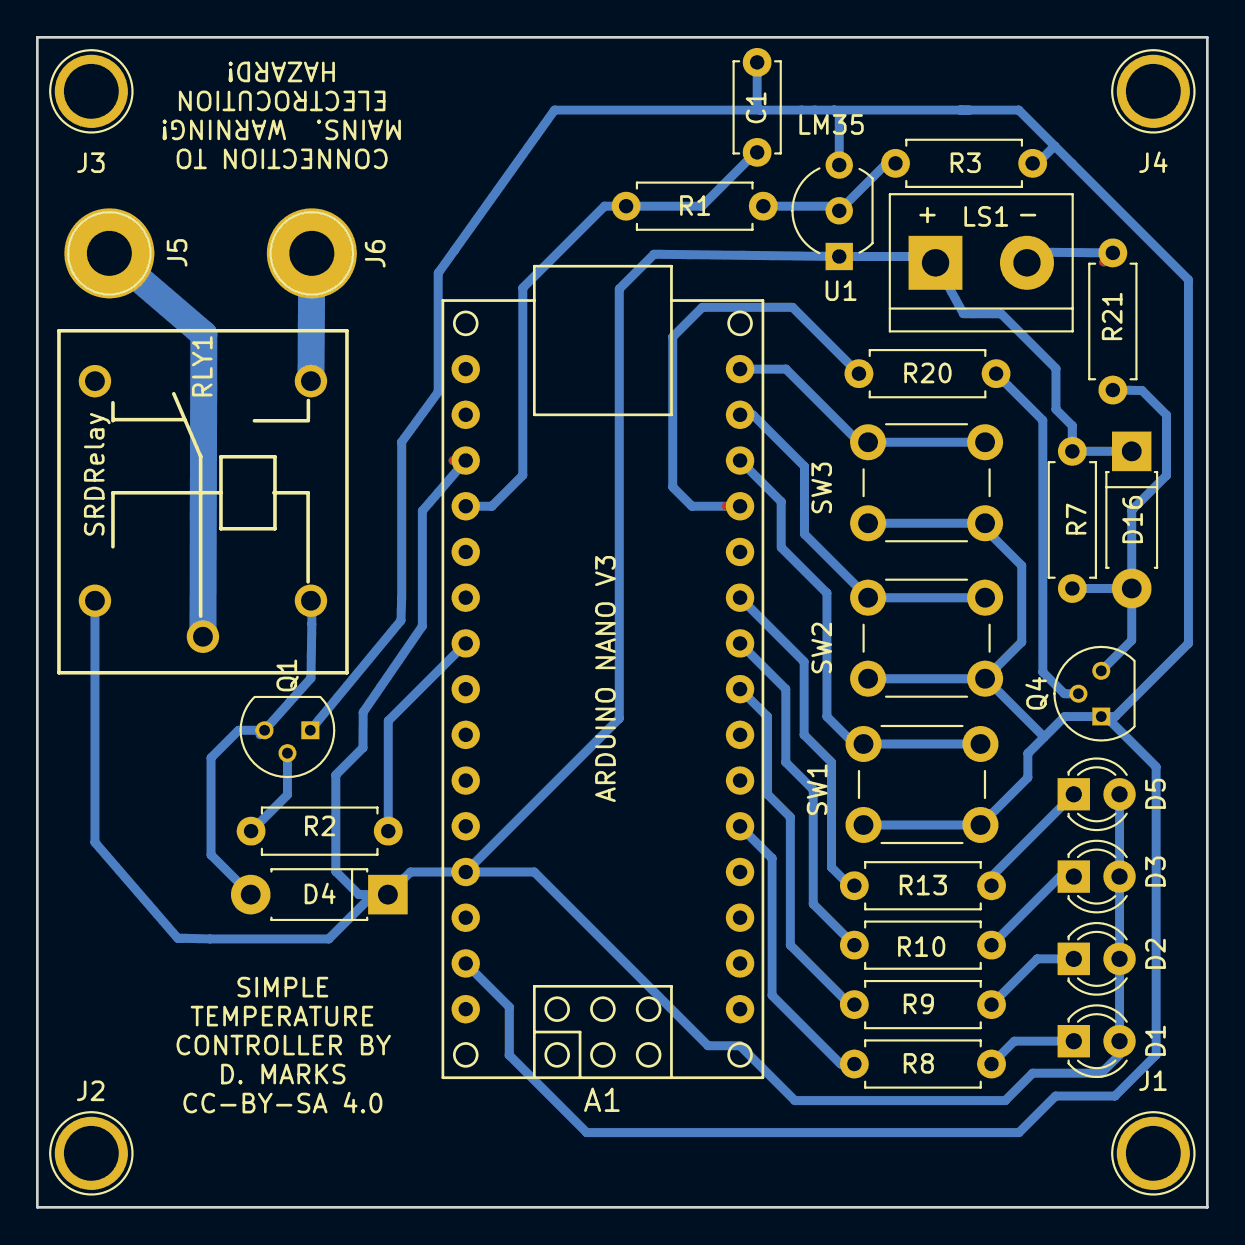
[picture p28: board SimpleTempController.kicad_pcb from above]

Board: 2 copper layers, 65.0 x 65.0 mm, 32 parts (0 on the bottom side), 24 nets.

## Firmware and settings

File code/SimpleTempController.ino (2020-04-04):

/* Simple Temperature Controller */

/*
 * Copyright (c) 2020 Daniel Marks

This software is provided 'as-is', without any express or implied
warranty. In no event will the authors be held liable for any damages
arising from the use of this software.

Permission is granted to anyone to use this software for any purpose,
including commercial applications, and to alter it and redistribute it
freely, subject to the following restrictions:

1. The origin of this software must not be misrepresented; you must not
   claim that you wrote the original software. If you use this software
   in a product, an acknowledgment in the product documentation would be
   appreciated but is not required.
2. Altered source versions must be plainly marked as such, and must not be
   misrepresented as being the original software.
3. This notice may not be removed or altered from any source distribution.
 */

#include <Arduino.h>
#include <EEPROM.h>

#define PINLED1 2
#define PINLED2 5
#define PINLED3 6
#define PINLED4 7

#define PINBUTTON1 10
#define PINBUTTON2 11
#define PINBUTTON3 12

#define PINSPEAKER 9
#define PINRELAY 17

#define ANALOGLM35 A0
#define DIVISOR 500000u

#define EEPROM_CONFIGURATION_STORE_ADDRESS 0 

// These are in units of 0.01 C
#define TEMP_HYSTERESIS 100u
#define TEMP_FAULT 1000u

typedef enum _temp_parameter
{
  TEMP_60C =  1,
  TEMP_65C =  2,
  TEMP_70C =  3,
  TEMP_75C =  4,
  TEMP_80C = 5,
  TEMP_90C = 6,
  TEMP_100C = 7
} temp_parameter;

typedef enum _time_parameter
{
  TIME_10min =  1,
  TIME_20min =  2,
  TIME_30min =  3,
  TIME_45min =  4,
  TIME_60min =  5,
  TIME_90min =  6,
  TIME_120min = 7
} time_parameter;

typedef enum _hysteresis_parameter
{
  HYSTERESIS_1C =  1,
  HYSTERESIS_2C =  2,
  HYSTERESIS_3C =  3,
  HYSTERESIS_4C =  4,
  HYSTERESIS_5C =  5,
  HYSTERESIS_6C =  6,
  HYSTERESIS_7C =  7
} hysteresis_parameter;

const uint8_t temp_states[8] = { 0, 60, 65, 70, 75, 80, 90, 100 };
const uint8_t time_states[8] = { 0, 10, 20, 30, 45, 60, 90, 120 };
const uint8_t hysteresis_states[8] = { 0, 1, 2, 3, 4, 5, 6, 7 };
const uint8_t led_states[8] = { 0x00, 0x01, 0x02, 0x03, 0x05, 0x09, 0x0B, 0x0F };

typedef struct _work_settings
{
  temp_parameter temp_parm;
  time_parameter tim_parm;
  hysteresis_parameter hysteresis_parm;
} work_settings;

work_settings settings = { TEMP_70C, TIME_30min, HYSTERESIS_2C };

void updateEEPROM()
{
  EEPROM.put(EEPROM_CONFIGURATION_STORE_ADDRESS, settings);
}

void readEEPROM()
{
  EEPROM.get(EEPROM_CONFIGURATION_STORE_ADDRESS, settings);
  if ((settings.temp_parm < 1) || (settings.temp_parm > (sizeof(temp_states)/sizeof(uint8_t))))
      settings.temp_parm = TEMP_70C;
  if ((settings.tim_parm < 1) || (settings.tim_parm > (sizeof(time_states)/sizeof(uint8_t))))
      settings.tim_parm = TIME_30min;
  if ((settings.hysteresis_parm < 1) || (settings.hysteresis_parm > (sizeof(hysteresis_states)/sizeof(uint8_t))))
      settings.hysteresis_parm = HYSTERESIS_2C;
}
void beep_speaker(int frequency, int duration)
{
  uint16_t waitlen = DIVISOR / frequency;
  uint32_t inittime = millis();
  uint8_t st = 0;
  while (((uint32_t)(millis()-inittime)) < duration)
  {
     st ^= 1;
     digitalWrite(PINSPEAKER,st ? HIGH : LOW);
     delayMicroseconds(waitlen);
  }
  digitalWrite(PINSPEAKER,LOW);
}

volatile uint8_t curStateButton1 = HIGH;
volatile uint8_t curStateButton2 = HIGH;
volatile uint8_t curStateButton3 = HIGH;
volatile uint8_t constStateButton1 = 0;
volatile uint8_t constStateButton2 = 0;
volatile uint8_t constStateButton3 = 0;
volatile uint8_t pushedButton1 = false;
volatile uint8_t pushedButton2 = false;
volatile uint8_t pushedButton3 = false;

bool relayState = false;

ISR(TIMER2_COMPA_vect)
{
  uint8_t state;
  state = digitalRead(PINBUTTON1);
  if (curStateButton1 != state)
  {
    if ((++constStateButton1) >= 10)
    {
        curStateButton1 = state;
        if (state == LOW) pushedButton1 = true;
        constStateButton1 = 0;
    }
  } else constStateButton1 = 0;

  state = digitalRead(PINBUTTON2);
  if (curStateButton2 != state)
  {
    if ((++constStateButton2) >= 10)
    {
        curStateButton2 = state;
        if (state == LOW) pushedButton2 = true;
        constStateButton2 = 0;
    }
  } else constStateButton2 = 0;

  state = digitalRead(PINBUTTON3);
  if (curStateButton3 != state)
  {
    if ((++constStateButton3) >= 10)
    {
        curStateButton3 = state;
        if (state == LOW) pushedButton3 = true;
        constStateButton3 = 0;
    }
  } else constStateButton3 = 0;
}

bool button1Pushed()
{
  if (!pushedButton1) return false;
  pushedButton1 = false;
  return true;
}

bool button2Pushed()
{
  if (!pushedButton2) return false;
  pushedButton2 = false;
  return true;
}

bool button3Pushed()
{
  if (!pushedButton3) return false;
  pushedButton3 = false;
  return true;
}

void clearButtonPushed()
{
  pushedButton1 = false;
  pushedButton2 = false;
  pushedButton3 = false;
}

void setup_timer2(void)
{
  cli();
  TCCR2A = 0;
  TCCR2B = 0;
  TCNT2  = 0;
  OCR2A = 200;
  TCCR2A |= (1 << WGM21);
  TCCR2B |= (1 << CS22);   
  TIMSK2 |= (1 << OCIE2A);
  sei();
}

void setup() {
  Serial.begin(9600);

  digitalWrite(PINLED1,HIGH);
  pinMode(PINLED1,OUTPUT);
  digitalWrite(PINLED2,HIGH);
  pinMode(PINLED2,OUTPUT);
  digitalWrite(PINLED3,HIGH);
  pinMode(PINLED3,OUTPUT);
  digitalWrite(PINLED4,HIGH);
  pinMode(PINLED4,OUTPUT);
  digitalWrite(PINSPEAKER,LOW);
  pinMode(PINSPEAKER,OUTPUT);
  digitalWrite(PINRELAY,LOW);
  pinMode(PINRELAY,OUTPUT);

  pinMode(PINBUTTON1,INPUT_PULLUP);
  pinMode(PINBUTTON2,INPUT_PULLUP);
  pinMode(PINBUTTON3,INPUT_PULLUP);
  pinMode(ANALOGLM35,INPUT);

  setup_timer2();
  readEEPROM();
}

void setRelay(bool state)
{
  relayState = state;
  digitalWrite(PINRELAY,state);
}

void indicate_state(uint8_t state)
{
  uint8_t state_vals = led_states[state];
  digitalWrite(PINLED1, state_vals & 0x01 ? LOW : HIGH);
  digitalWrite(PINLED2, state_vals & 0x02 ? LOW : HIGH);
  digitalWrite(PINLED3, state_vals & 0x04 ? LOW : HIGH);
  digitalWrite(PINLED4, state_vals & 0x08 ? LOW : HIGH);
}

bool checkButtonState(volatile uint8_t &state, uint8_t waittime)
{
  for (uint8_t i=0;i<waittime;i++)                 // make the button held down for 2 seconds
  {
    indicate_state(i & 0x01 ? 7 : 0);
    if (state == HIGH) 
    {
      indicate_state(0);
      return false;
    }
    delay(100);
  }
  return true;
}

bool setHysteresis(void)
{
  uint8_t st = 0;
  if (!checkButtonState(curStateButton3,50)) return false;
  setRelay(false);  // turn off heater
  digitalWrite(PINLED1,HIGH);
  digitalWrite(PINLED2,HIGH);
  digitalWrite(PINLED3,HIGH);
  digitalWrite(PINLED4,HIGH);
  for (uint8_t i=0;i<5;i++)
  {
    digitalWrite(PINLED1,LOW);
    beep_speaker(400,300);
    digitalWrite(PINLED1,HIGH);
    digitalWrite(PINLED4,LOW);
    beep_speaker(700,300);
    digitalWrite(PINLED4,HIGH);
    digitalWrite(PINLED2,LOW);
    beep_speaker(500,300);
    digitalWrite(PINLED2,HIGH);
    digitalWrite(PINLED3,LOW);
    beep_speaker(600,300);
    digitalWrite(PINLED3,HIGH);
  }
  digitalWrite(PINLED2,HIGH);
  clearButtonPushed();
  for (;;)
  {
    st ^= 1;
    indicate_state(st ? settings.hysteresis_parm : 0);
    delay(300);
    if (button1Pushed()) 
    {
      beep_speaker(400,300);
      delay(300);
      beep_speaker(400,300);
      indicate_state(0);
      updateEEPROM();
      break;
    }
    if (button2Pushed())
    {
      beep_speaker(600,300);
      settings.hysteresis_parm = ((uint8_t)settings.hysteresis_parm)+1;
      if (settings.hysteresis_parm >= (sizeof(hysteresis_states)/sizeof(uint8_t)))
        settings.hysteresis_parm = 1;
    }
  }
  return true;
}

void setTemp(void)
{
  uint8_t st = 0;
  if (!checkButtonState(curStateButton1,50)) return;
  setRelay(false);  // turn off heater
  for (uint8_t i=0;i<5;i++)
  {
    digitalWrite(PINLED1,LOW);
    beep_speaker(400,300);
    digitalWrite(PINLED1,HIGH);
    digitalWrite(PINLED2,LOW);
    beep_speaker(500,300);
    digitalWrite(PINLED2,HIGH);
    digitalWrite(PINLED3,LOW);
    beep_speaker(600,300);
    digitalWrite(PINLED3,HIGH);
    digitalWrite(PINLED4,LOW);
    beep_speaker(700,300);
    digitalWrite(PINLED4,HIGH);
  }
  digitalWrite(PINLED3,HIGH);
  clearButtonPushed();
  for (;;)
  {
    st ^= 1;
    indicate_state(st ? settings.temp_parm : 0);
    delay(300);
    if (button1Pushed()) 
    {
      beep_speaker(400,300);
      delay(300);
      beep_speaker(400,300);
      indicate_state(0);
      updateEEPROM();
      break;
    }
    if (button2Pushed())
    {
      beep_speaker(600,300);
      settings.temp_parm = ((uint8_t)settings.temp_parm)+1;
      if (settings.temp_parm >= (sizeof(temp_states)/sizeof(uint8_t)))
        settings.temp_parm = 1;
    }
    if (button3Pushed() && setHysteresis()) break;
  }
}

void setDuration(void)
{
  uint8_t st = 0;
  if (!checkButtonState(curStateButton2,50)) return;
  setRelay(false);  // turn off heater
  for (uint8_t i=0;i<5;i++)
  {
    digitalWrite(PINLED1,LOW);
    digitalWrite(PINLED2,HIGH);
    digitalWrite(PINLED3,HIGH);
    digitalWrite(PINLED4,LOW);
    beep_speaker(400,600);
    digitalWrite(PINLED1,HIGH);
    digitalWrite(PINLED2,LOW);
    digitalWrite(PINLED3,LOW);
    digitalWrite(PINLED4,HIGH);
    beep_speaker(500,600);
  }
  digitalWrite(PINLED3,HIGH);
  clearButtonPushed();
  for (;;)
  {
    st ^= 1;
    indicate_state(st ? settings.tim_parm : 0);
    delay(300);
    if (button1Pushed()) 
    {
      beep_speaker(400,300);
      delay(300);
      beep_speaker(400,300);
      indicate_state(0);
      updateEEPROM();
      break;
    }
    if (button2Pushed())
    {
      beep_speaker(500,300);
      settings.tim_parm = ((uint8_t)settings.tim_parm)+1;
      if (settings.tim_parm >= (sizeof(time_states)/sizeof(uint8_t)))
        settings.tim_parm = 1;
    }
  }
}

#define NUMBER_OF_AVERAGES 24
#define AD_MAX_VOLTAGE 50000lu
#define AD_MAX_VALUE 1024lu
#define AD_CELSIUS_PER_VOLT 1lu

// temperature is returned in units of 0.01 deg C, so 
// 20 deg C = 2000 
uint16_t read_temperature_celsius(void)
{
  uint32_t sample = 0;
  for (uint8_t i=0;i<NUMBER_OF_AVERAGES;i++)
      sample += analogRead(ANALOGLM35);
  sample = (sample*(AD_MAX_VOLTAGE*AD_CELSIUS_PER_VOLT))/(AD_MAX_VALUE*NUMBER_OF_AVERAGES);
  return (uint16_t) sample;
}

bool temperature_probe_working(void)
{
  uint16_t temp = read_temperature_celsius();

  // if the temperature is less than 2C or greater than 200C
  // then the temperature probe is not working
  return ((temp >= 200) && (temp < 20000));
}

void indicate_error(uint8_t code, uint16_t freq)
{
  clearButtonPushed();
  while ((!button1Pushed()) && (!button2Pushed()) && (!button3Pushed()))
  {
    indicate_state(code);
    beep_speaker(freq,500);
    indicate_state(0);
    delay(500);
  }
  indicate_state(0);
  clearButtonPushed();
}

void indicate_response(uint8_t code, uint16_t freq)
{
  clearButtonPushed();
  for (uint8_t i=0;i<3;i++)
  {
    indicate_state(code);
    beep_speaker(freq,500);
    indicate_state(0);
    delay(500);
  }
  indicate_state(0);
  clearButtonPushed();
}

bool temperature_probe_error(void)
{
  if (temperature_probe_working()) return false;
  setRelay(false);  // turn off heater
  indicate_error(5,200);
  return true;
}

void doHeating(void)
{
  if (!checkButtonState(curStateButton3,5)) return;
  if (temperature_probe_error()) return;

  uint32_t total_heating_time = ((uint32_t)time_states[settings.tim_parm])*(60lu*1000lu);
      // total heating time milliseconds
  uint16_t temperature_target = ((uint16_t)temp_states[settings.temp_parm])*100u;
  uint16_t temperature_low = ((uint16_t)temp_states[settings.temp_parm])*100u-(100u*hysteresis_states[settings.hysteresis_parm]);
      // do not turn heater off until the temperature is 1 C below target
  uint16_t temperature_high = ((uint16_t)temp_states[settings.temp_parm])*100u+(100u*hysteresis_states[settings.hysteresis_parm]);
      // do not stop heater until the temperature is 1 C above target
  uint16_t temperature_low_error = ((uint16_t)temp_states[settings.temp_parm])*100u-TEMP_FAULT;
      // if temp is less than 10 C below target after heating, there's a problem!
  uint16_t temperature_high_error = ((uint16_t)temp_states[settings.temp_parm])*100u+TEMP_FAULT;
      // if temp is greater than 10 C above target, there's a problem!
  Serial.print("time dur=");
  Serial.print(total_heating_time);
  Serial.print(" temp dur=");
  Serial.println(temperature_target);

  indicate_state(5);
  beep_speaker(400,1000);
  indicate_state(0);
  clearButtonPushed();

  // begin heating cycle
  setRelay(true);          // turn on heater
  uint8_t st = 0;
  for (;;)
  {
    uint16_t current_temp;
    if (temperature_probe_error()) return;
    current_temp = read_temperature_celsius();
    Serial.print("current temp = ");
    Serial.println(current_temp);
    if (current_temp > temperature_high_error)
    {
        setRelay(false);  // turn off heater
        indicate_error(5,200);
        return;
    }
    if (current_temp > temperature_target) break;
    st ^= 1;
    digitalWrite(PINLED1, st ? LOW : HIGH);
    digitalWrite(PINLED2, st ? HIGH : LOW);
    digitalWrite(PINLED3, st ? LOW : HIGH);
    digitalWrite(PINLED4, st ? HIGH : LOW);
    delay(300);
    if (button1Pushed())
    {
      if (checkButtonState(curStateButton1,10))
      {
        setRelay(false); 
        indicate_response(7,300);
        return;
      }
    }
  }
  // reached target temp, now start counting time
  uint32_t start_time = millis();
  for (;;)
  {
    uint16_t current_temp;
    uint32_t elapsed_time = (uint32_t)(millis() - start_time);
    if (temperature_probe_error()) return;

    if (elapsed_time >= total_heating_time) break; // we're done!
    if (button1Pushed())
    {
      if (checkButtonState(curStateButton1,10))
      {
        setRelay(false); 
        indicate_response(7,300);
        return;
      }
    }    
    current_temp = read_temperature_celsius();
    if ((current_temp < temperature_low_error) || (current_temp > temperature_high_error))
    {
        setRelay(false);  // turn off heater
        indicate_error(5,200);
        return;
    }
    if (current_temp > temperature_high) setRelay(false);
    if (current_temp < temperature_low) setRelay(true);

    uint8_t frac = (elapsed_time*4u) / total_heating_time;
    Serial.print("current temp2 = ");
    Serial.print(current_temp);
    Serial.print(" elapsed_time = ");
    Serial.print(elapsed_time);
    Serial.print(" total_heating_time = ");
    Serial.print(total_heating_time);
    Serial.print(" frac = ");
    Serial.println(frac);
    st ^= 1;
    int flashState = relayState ? (st ? HIGH : LOW) : LOW;
    if (frac == 0)
    {
      digitalWrite(PINLED1, flashState);
      digitalWrite(PINLED2, HIGH);
      digitalWrite(PINLED3, HIGH);
      digitalWrite(PINLED4, HIGH);
      
    } else if (frac == 1)
    {
      digitalWrite(PINLED1, LOW);
      digitalWrite(PINLED2, flashState);
      digitalWrite(PINLED3, HIGH);
      digitalWrite(PINLED4, HIGH);
    } else if (frac == 2)
    {
      digitalWrite(PINLED1, LOW);
      digitalWrite(PINLED2, HIGH);
      digitalWrite(PINLED3, flashState);
      digitalWrite(PINLED4, HIGH);
    } else if (frac == 3)
    {
      digitalWrite(PINLED1, LOW);
      digitalWrite(PINLED2, HIGH);
      digitalWrite(PINLED3, HIGH);
      digitalWrite(PINLED4, flashState);
    }
    delay(300);
  }
  setRelay(false); 
  uint8_t i = 0;
  clearButtonPushed();
  for (;;)
  {
    indicate_state(0);
    delay(1000);
    if ((button1Pushed()) || (button2Pushed()) || (button3Pushed())) break;
    indicate_state(7);
    if (i < 10)
    {
        i++;
        beep_speaker(400,1000);
    } else delay(1000);
    if ((button1Pushed()) || (button2Pushed()) || (button3Pushed())) break;
  }    
  clearButtonPushed();
  indicate_state(0);
}

void loop() {
  static uint8_t st = 0;
  st ^= 0x01;
  setRelay(false); 
  digitalWrite(PINLED1,st ? LOW : HIGH);
  digitalWrite(PINLED2,st ? LOW : HIGH);
  digitalWrite(PINLED3,st ? HIGH : LOW);
  digitalWrite(PINLED4,st ? HIGH : LOW);
  if (button1Pushed()) setTemp();
  if (button2Pushed()) setDuration();
  if (button3Pushed()) doHeating();
  delay(300);
}

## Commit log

2020-04-13 More Creepage
    [SimpleTempController-B.Cu.gbr, SimpleTempController-B.Mask.gbr, SimpleTempController-B.SilkS.gbr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]
2020-04-13 Even more creepage
    [SimpleTempController-B.Cu.gbr, SimpleTempController-B.Mask.gbr, SimpleTempController-B.SilkS.gbr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]
